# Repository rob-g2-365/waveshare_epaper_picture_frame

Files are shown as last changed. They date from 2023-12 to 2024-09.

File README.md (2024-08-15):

# Waveshare Epaper Picture Frame

# Table of Contents
* [Introduction](#Introduction)
* [Knowledge Assumptions](#Knowledge-Assumptions)
* [File List](#File-List)
* [Specifications](#Specifications)
* [Parts List](#Parts-List)
* [Other Equipment Needed](#Other-Equipment-Needed)
* [Printing Instructions](#Printing-Instructions)
* [PCB Board Instructions](#PCB-Board-Instructions)
* [Assembly Instructions](#Assembly-Instructions)
* [Arduino Code ](#Arduino-Code)
* [Python Code](#Python-Code)
* [SD Card](#SD-Card)
* [Testing and Putting it Together](#Testing-and-Putting-it-Together)
* [Battery Life and Power Consumption](#Battery-Life-and-Power-Consumption)
* [Additional Resources](#Additional-Resources)

## Introduction

This project displays an image on an e-paper picture frame.  The picture switches once per day.  Included are the list of materials and how to build it.

E Picture frame display

## Knowledge Assumptions
I am assuming in this project that the user knows how to do the following:

* Read an electrical schematic.
* Basic soldering of through-hole components.
* Configure and build a project using the Arduino IDE.
* Slice a 3d Model and send it to a 3d printer.
* Put brass inserts into plastic using a soldering iron.
* Run a Python script.

## File List

* [Documentation](./docs)
* [Gerber files](./gerber)
* [STL Files](./stl)
* [Freecad code](./freecad)
* [Arduino IDE code](./arduino)
* [Convert Images Script](./convert_images)
* [Sample SD Card Image](./sdcard_image)
* [License file](.license)

## Specifications

* Display Size 5x7 inches or 10x18cm.
* Battery life should be about a year with alkaline batteries.

## Parts List

### Basic Parts
| Item | Quantity  		 | Notes |
| :--- | :--- 		 | :--- |
| PLA | 400g 		 | Used just plain black PLA |
| Picture frame  | 1 | [Used 5x7 Vertical Side Natural Frame by Threshold from Target](https://www.target.com/p/5--34--x-7--34--vertical-sides-natural-frame-antique-wood---threshold--8482-/-/A-54562757) |
| Solder | Small Amount | |

### Fasteners

| Item | Quantity  		 | Notes |
| :--- | :--- 		 | :--- |
| M2 x 6mm Phillips Flat Countersunk Head Machine Screws	| 2 |  |
| M2.5 x 8mm Phillips flathead Machine Screws | 2 |  |
| \#4 x 1/2 inch Wood Screws | 5 | Alternative use M3 x 15mm Woodscrews |
| M2.5 x 5mm Pan Phillips Cross Head Machine screws | 12 |  You could just use the flathead screws for all screws M2.5 screws |
| M2 x 4mm Brass Inserts	 | 14 | |
| M2.5 x 5.8mm Brass Inserts | 12 |  There is room for longer inserts. |

### Electrical Parts

Note that all electronic parts are through-hole components.  Note that many substitutes can be used for the resistors, capacitors, and diode.

| Item 									 | Part Number 																						| Quantity  |
| :--- 									 | :--- 																				| :--- |
| Waveshare 7.3 inch ACeP 7-Color E-Paper 800x600 | [7.3 inch e-Paper Hat (F)](https://www.waveshare.com/product/displays/e-paper/7.3inch-e-paper-hat-f.htm) | 1 |
| MicroSD Card | MicroSD Card | 1 |
| MicroSD Card Adapter for Arduino | [MicroSD Card Adapter](https://www.amazon.com/Storage-Memory-Shield-Module-Arduino/dp/B01IPCAP72) | 1 |
| 3 AAA Battery Holder | [3 AAA Battery Holder](https://www.amazon.com/Velleman-BH431A-Battery-Holder-AAA-Cell/dp/B003TZDNN4) | 1 |  
| ATmega328-P-PU Arduino Bootloader | [3647-ATMEGA328P-PUArduinoBootloader-ND](https://www.digikey.com/en/products/detail/universal-solder-electronics-ltd/ATMEGA328P-PU-Arduino-Bootloader/16822123)  | 1 | 
| 28 Pin DIP Socket | [ICM-328-1-GT-HT](https://www.digikey.com/en/products/detail/adam-tech/ICM-328-1-GT-HT/9832998) | 1 |
| PMOS - LP0701N3-G | [LP0701N3-G-ND](https://www.digikey.com/en/products/detail/microchip-technology/LP0701N3-G/4902364) | 1 |
| 22pF Capacitor | [K220J15C0GF5TL2](https://www.digikey.com/en/products/detail/vishay-beyschlag-draloric-bc-components/K220J15C0GF5TL2/286459) | 2 |
| 100nF	Capacitor 							 | [K104K15X7RF5TL2](https://www.digikey.com/en/products/detail/vishay-beyschlag-draloric-bc-components/K104K15X7RF5TL2/286538) | 3 |
| Diode General Purpose | [BAW75-TAP](https://www.digikey.com/en/products/detail/vishay-general-semiconductor-diodes-division/BAW75-TAP/4825763) | 1 |
| 10K Resistor | [CF14JT10K0](https://www.digikey.com/en/products/detail/stackpole-electronics-inc/CF14JT10K0/1741265) | 1 |
| 100K Resistor | [CF14JT100K](https://www.digikey.com/en/products/detail/stackpole-electronics-inc/CF14JT100K/1741263) | 2 | 
| SW_Push SWITCH TACTILE SPST | [B3F-1000](https://www.digikey.com/en/products/detail/omron-electronics-inc-emc-div/B3F-1000/33150) | 1 | 
| 16Mhz 20pF Crystal | [ECS-160-20-1X](https://www.digikey.com/en/products/detail/ecs-inc/ECS-160-20-1X/827525) | 1 |

We need a package of straight DuPont-style male row connectors in order to make the 1x2, 1x6, and 1x8 Connectors.  Also (10Cm) short multicolor Dupont Female to Female wires.

Note that the Micro SD Card doesn't need much capacity.  A 1Gb Micro SD Card should work.

## Other Equipment Needed

### Other Hardware Needed

* 3D Printer
* Soldering Iron
* [Arduino FTDI USB to Serial 5v Programmers](https://www.amazon.com/Serial-Adapter-Female-FT232RL-Windows/dp/B07RBK2P47) 

Also, it is a good idea to have troubleshooting equipment such as a multimeter and something to decode the SPI bus traffic.

### Software Needed

Need the software [Arduino IDE](https://www.arduino.cc/en/software) to build and download the code. I used version 2.1.0, but the latest version probably would work for you.

#### Arduino IDE Packages

| Package 														| Owner 			  | Current Version |
| :--- 														| :---  			  | :--- |
| Arduino Builtin | Arduino | Built Into IDE  |
| [SD](https://www.arduino.cc/reference/en/libraries/sd/) 	| Arduino SparkFun | 1.2.4 |
| [LowPower_LowPowerLab](https://www.arduino.cc/reference/en/libraries/lowpower_lowpowerlab/)  | LowerPowerLab | 2.2 			|
| [EEPROM](https://docs.arduino.cc/learn/built-in-libraries/eeprom)	 | Arduino | Built Into IDE  |
| [SPI](https://www.arduino.cc/reference/en/language/functions/communication/spi/) | Arduino | Built Into IDE  |

### Python Environment

I used Python 3.9 with the Pillow (Python Image Library) 9.3.0 package installed.  The latest of each should work.

#### Optional Software

| Package 				| Version Used |
| :--- 				| :---  	 |
| Freecad | 0.21.2 |
| KiCad | 7.0 |

## Printing Instructions

### Printer Settings

| Settings  |  Used |  Notes |
| :--- | :--- | :--- |
| Material  | PLA | |
| Nozzle | 0.4mm | |
| Layer Height | 0.2mm | |
| Walls | 5 | Needed for Brass Inserts |
| Infill | 20% | |
| Supports  | Only Touching Build plate | |

### 3D Printed Parts List

| Part 	|  Picture |
| :--- 	| :--- |
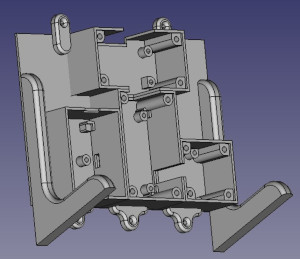
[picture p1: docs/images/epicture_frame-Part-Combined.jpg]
Main Part
| Main Part 	|  |
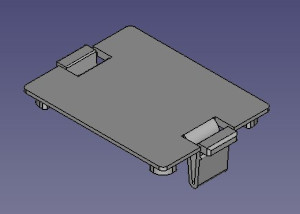
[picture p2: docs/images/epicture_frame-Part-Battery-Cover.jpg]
Battery Cover
| Battery Cover 	|   |
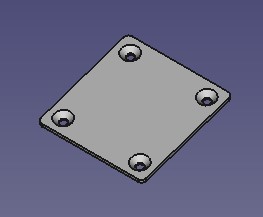
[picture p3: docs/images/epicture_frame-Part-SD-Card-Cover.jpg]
SD Card Cover
| SD Card Cover 	|   |
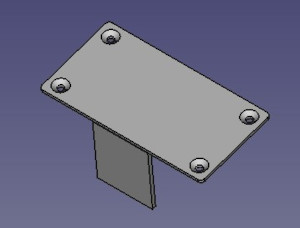
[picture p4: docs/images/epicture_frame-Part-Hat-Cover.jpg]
Display HAT Cover
| Display HAT Cover |  |
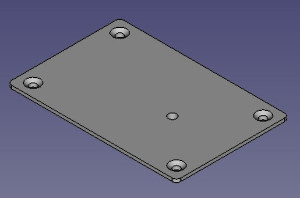
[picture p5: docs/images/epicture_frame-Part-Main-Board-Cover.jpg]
Main Board Cover
| Main Board Cover  |   | 
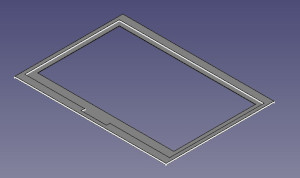
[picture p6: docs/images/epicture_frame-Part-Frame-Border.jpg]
Frame Border
| Frame Border |   |

## PCB Board Instructions

Gerber files are listed in the gerber directory.    I used OshPark to create the PCBs, but you should be able to use other vendors.

## Assembly Instructions

### Insert the M2.5 Brass Inserts into the Following Holes

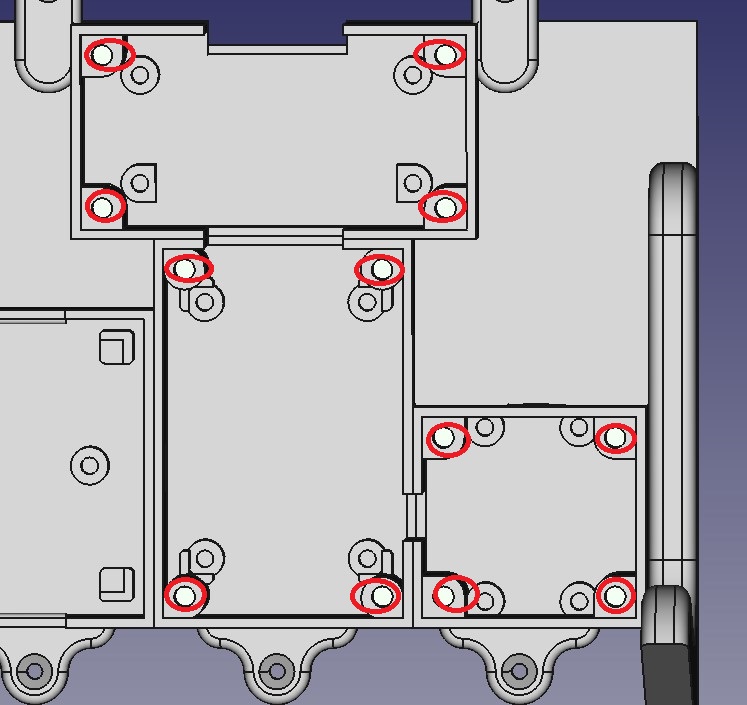
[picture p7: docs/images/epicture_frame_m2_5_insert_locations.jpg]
M2.5 Brass Insert Locations


Use a solder gun to insert the brass inserts.

### Insert the M2 Brass Inserts into the Following Holes

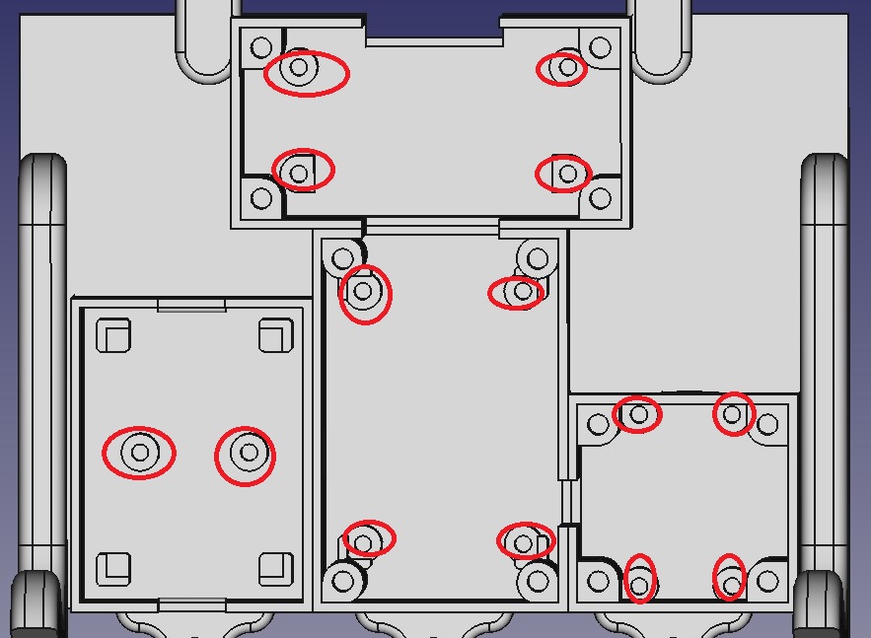
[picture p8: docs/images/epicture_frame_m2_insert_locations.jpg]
M2 Brass Insert Locations


### Solder Components to PCB Board

Solder components to the PCB board.  The silkscreen shows the Component number location.

| Component Number | Part  |
| :--- | :---  |
| C1, C2 | 22pF  | 
| C3, C4, C5 | 100nF |
| D1 | General Purpose Diode |
| J1, J2 | Male Connector 01x06 Pin |
| J3	 | Male Connector 01x08 Pin |
| J4	 | Male Connector 01x02 Pin |
| Q1	 | PMOS - LP0701N3-G |
| R1 | 10K Resistor |
| R2, R3	 | 100K Resistor |
| SW1 | Push button switch |
| U1	 | 28 Pin Connector for ATmega328-P |
| Y1	 | 16Mhz Crystal |

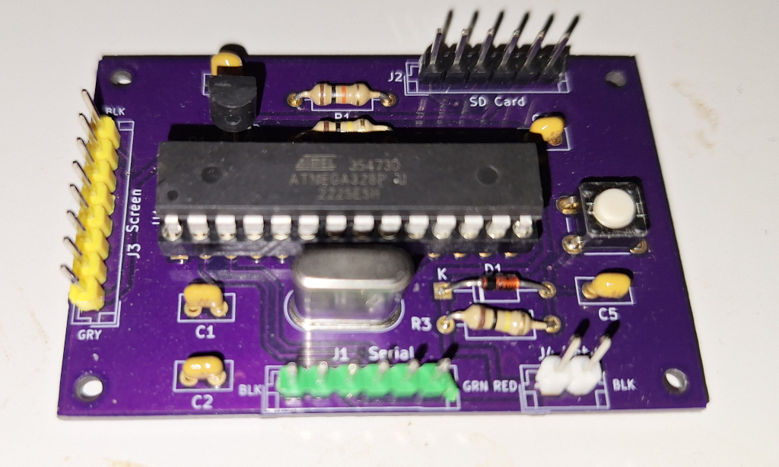
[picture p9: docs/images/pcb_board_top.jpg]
PCB board


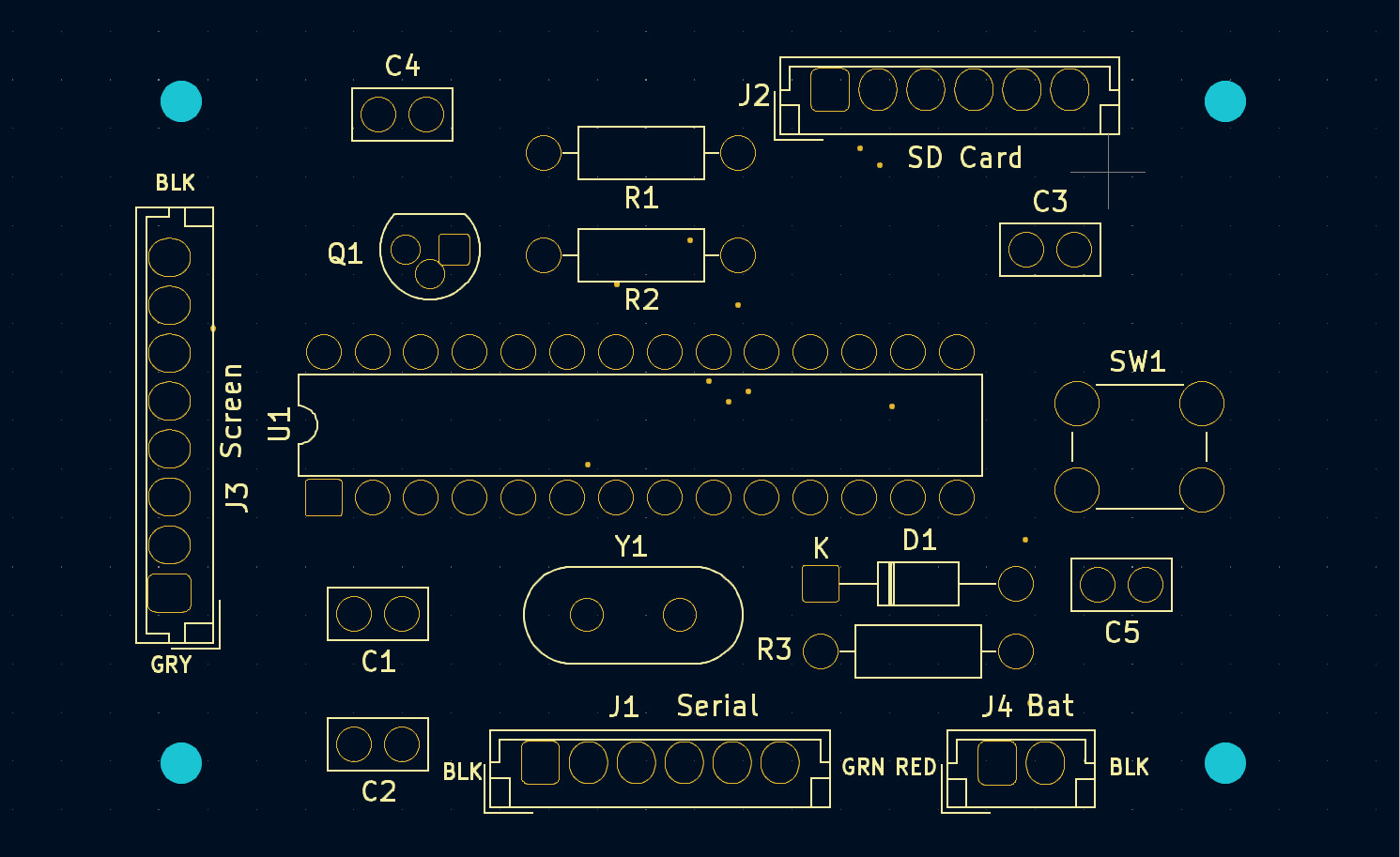
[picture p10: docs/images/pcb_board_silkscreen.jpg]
PCB board Silk Screen


### Assemble the Main Part to Frame

Remove the original back assembly from the picture frame. We do not need the back of the picture frame, the screws, or the stand.  We only need the picture frame and the glass.

Mark Drill Holes.  (See frame back picture)
Drill holes into the picture frame using a 5/64 or 2mm drill bit.

Remove any stickers from the glass. Clean glass the glass using glass cleaner or isopropyl alcohol.   Ensure that no fingerprints are on the inside glass. 

Assemble in the following order:

1.  Wooden Frame
2.  Glass
3.  3D Printed Frame border
4.  E-paper display (Be sure the protective covering is removed and the e-paper display ribbon cable is at the top.)
5.  3D Printed Main Body

Use the #4 wood screw holes to attach the 3D Printed main body to the wooden picture frame.

### Put Boards into Main Picture Frame

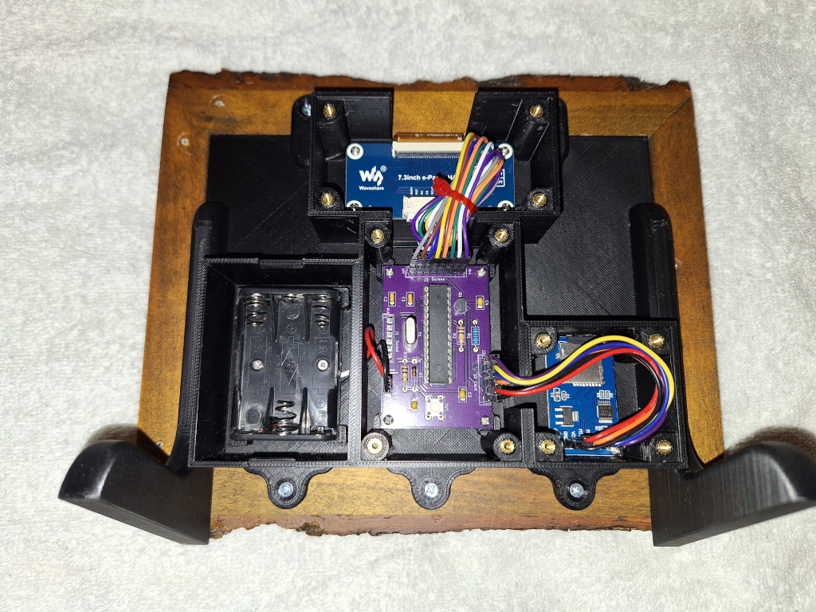
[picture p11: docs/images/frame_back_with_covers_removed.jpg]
Frame Back


### Connect the Ribbon Cable to the E-Hat

The extension cable for the e-paper display is not needed.   Connect the ribbon cable from the display to the e-hat.  Use M2 roundhead screws to attach the e-hat.

### Attach the Battery Case

Push battery wires through the holes in the main body.  Attach the battery case using M2 Flathead screws.

### Attach the Other Components to the Main Board

SD Card Adapter and Main Board used M2 Roundhead screws.  Be sure that the hole in the main body for the SD Card matches the SD Card slot.

Attach the main PCB board.  Ensure that the J3 screen is next to the hat connector and the SW1 is at the bottom of the display. 

### Make Connections to PCB Board

Attach the battery to J4.  PCB board is marked red for positive and black for negative.

Attach SD card connections to J2.  Chip select is closest to R1.  Please double-check [schematic](./docs/schematic.pdf).

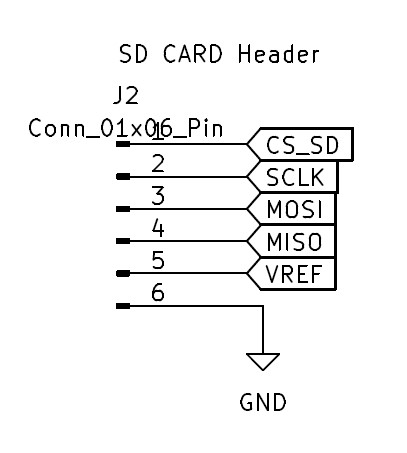
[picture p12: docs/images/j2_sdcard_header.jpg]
J2 SD Card Header


Attach the Waveshare e-hat SPI connections to J3.  Gray should match GRY on the board.  Note that the BLK wire may be purple.

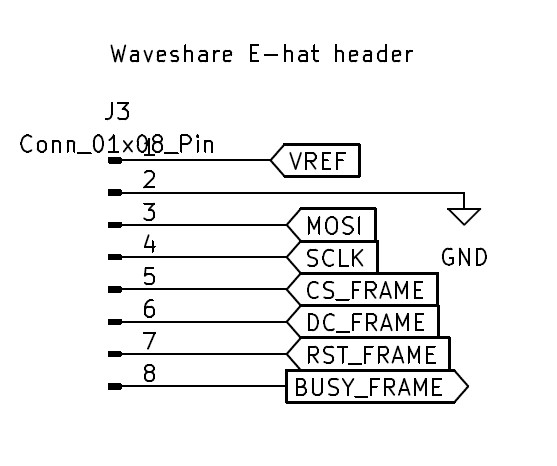
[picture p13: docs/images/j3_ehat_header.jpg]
J3 Waveshare E-hat header


## Arduino Code 

### Arduino Code Overview

I had to make a couple of changes to the Waveshare drivers.  They are:

   A.  Changes with Waveshare drivers (SPI frequency and chips select)
   B.  Reduced the SPI clock speed.

### Download Instructions

Use Board type "Arduino Uno"

Attach FTDI USB to serial connector to J1 serial connector. 

### Enable Serial Debug

If you run into problems, you may want to enable serial debugging.  To enable serial debug out, uncomment line 50. 

<pre>
// Include this flag to turn on serial logging.
// #define SERIAL_DEBUG
</pre>

The last failure is saved in the EEPROM.  When booting, the error code is outputted over the serial port.   The error codes are listed in line 36 of debug.h.
<pre>
#define ERRORCODE_TEST                        0
#define ERRORCODE_EPAPER_INIT_FAILED          0x101
.
.
</pre>

## Python Code

### Preprocessing Portrait Images

Images that are formatted as portrait may need to be cropped so that faces and important details may be shown.

### Python Command-line Arguments

<pre>
	convert_images.py &lt;Source Directory&gt;  &lt;Destinations Directory&gt;
</pre>	
	
This command converts images from the source directory or its children into the destination directory.

Images in the destination directory are listed in the following order:  pic_000.bmp, pic_001.bmp, pic_002.bmp, etc.

This program also does the following:  

1.  Auto-adjusts the contrast.
2.  Increases the saturation so the images don't look washed out.
3.  Mirrors the image to looks correct when viewed from the picture frame.
4.  Crops the image so the image size is correct.
5.  Dithers the images so that only seven colors are needed to display the image.
6.  Randomizes the image's order.

## SD Card

### Sample SD Card Image

A sample SD Card image is located in:

Sample SDCard Image

### SD Card Format and Files

The Micro SD Card capacity can be small since the images don't occupy much space.  Format a Micro SD Card using Fat32.  Copy the processed image files to the root of the Micro SD Card.

Insert the Micro SD Card into the Micro SDCard Adapter for Arduino.

## Testing and Putting it Together

Verify that the image appears on the e-paper display.

Attach the 3D-printed covers.  

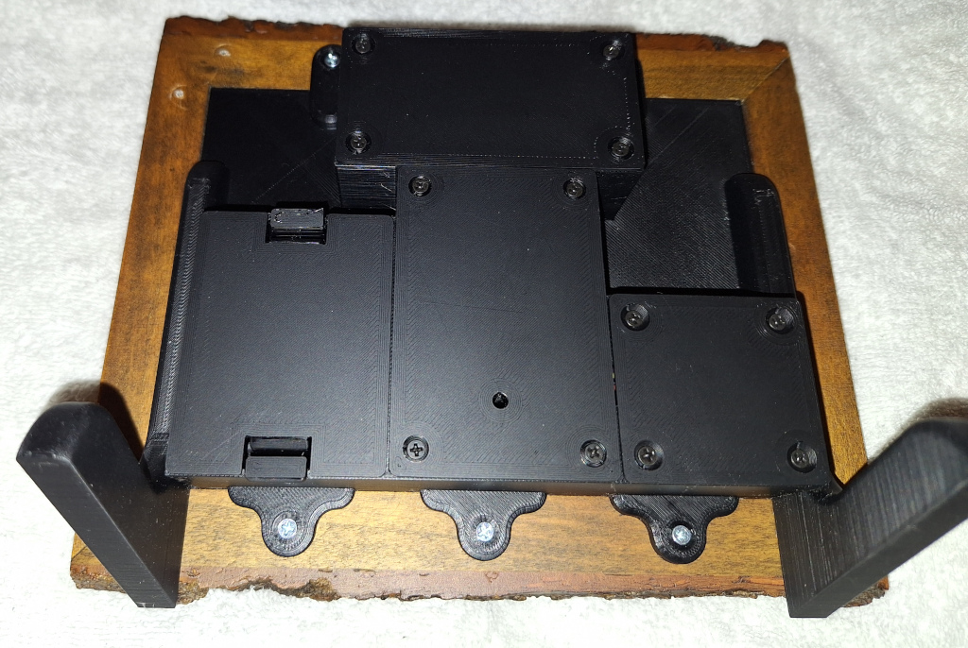
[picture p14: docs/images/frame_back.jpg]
Picture Frame Back


## Battery Life and Power Consumption

It takes about 134 seconds to change the image on the screen.  During this time, it uses approximately 40mA. 

$$ = 134 (seconds/switch) * 40 (mA) / 3600 (seconds/hour) $$

$$ = 1.5 (mAh/switch) $$

When idle, the current draw is about 10 uA.

$$ =  24 (hours) * 0.01 (mA) $$

$$ = 0.3 (mAh) $$

An approximate alkaline AAA battery life is about 1200mAh.  However, the picture frame cannot use the full capacity of the battery.  
Once the voltage goes below 3.8v, 1.25v per cell, the picture frame will stop working.  This is about 50% of the capacity.

Therefore, the battery life for the picture frame is:

$$ = 1200 mAh * 50% / 1.8 (mAh/ day) $$

$$ = 333 (days) $$

## Possible improvements.

### Use a ultra low I<sub>Q</sub> Boost Converter

An ultra-low I<sub>Q</sub> boost converter is one option for more battery life.  This will allow the battery pack voltage to be functional down 
to 2.7v, which is using the battery's full capacity. I don't know if using the full capacity of the battery will offset the leakage power lost through the boost converter.

## Additional Resources

[Waveshare 7.3inch e-Paper HAT (F) Manual](https://www.waveshare.com/wiki/7.3inch_e-Paper_HAT_(F))

[e Paper with Arduino and Raspberry Pi](https://www.youtube.com/watch?v=4onIqHClh2s&t=601s)

[Trolling My Mom With an E-Paper Picture](https://youtu.be/YawP9RjPcJA)

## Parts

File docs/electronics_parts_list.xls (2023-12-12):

Source: | C:\work\arduino\kicad\epaper_board_layout\epaper_board_layout\epaper_board_layout.kicad_sch
Date: | 4/21/2023 1:44:44 PM
Tool: | Eeschema 7.0.1
Generator: | C:\Program Files\KiCad\7.0\bin\scripting\plugins/bom_csv_grouped_by_value.py
Component Count: | 17
Collated Components:
Item | Qty | Reference(s) | Value | LibPart | Footprint | Datasheet | DNP | Sim.Device | Sim.Pins | Sim.Type
1 | 2 | C1, C2 | 22pF | Device:C | Capacitor_THT:C_Disc_D5.0mm_W2.5mm_P2.50mm | https://www.digikey.com/en/products/detail/vishay-beyschlag-draloric-bc-components/K220J10C0GF5UH5/2821614
2 | 3 | C3, C4, C5 | 100nF | Device:C | Capacitor_THT:C_Disc_D5.0mm_W2.5mm_P2.50mm | https://www.digikey.com/en/products/detail/vishay-beyschlag-draloric-bc-components/K104K15X7RF53H5G/13279844
3 | 1 | D1 | D | Device:D | Diode_THT:D_DO-35_SOD27_P10.16mm_Horizontal | https://www.digikey.com/en/products/detail/vishay-general-semiconductor-diodes-division/BAW75-TAP/4825763 |  | D | 1=K 2=A
4 | 2 | J1, J2 | Conn_01x06_Pin | Connector:Conn_01x06_Pin | Connector_JST:JST_EH_B6B-EH-A_1x06_P2.50mm_Vertical | ~
5 | 1 | J3 | Conn_01x08_Pin | Connector:Conn_01x08_Pin | Connector_JST:JST_EH_B8B-EH-A_1x08_P2.50mm_Vertical | ~
6 | 1 | J4 | Conn_01x02_Socket | Connector:Conn_01x02_Socket | Connector_JST:JST_EH_B2B-EH-A_1x02_P2.50mm_Vertical | ~
7 | 1 | Q1 | PMOS - LP0701N3-G | Simulation_SPICE:PMOS | Package_TO_SOT_THT:TO-92 | https://www.digikey.com/en/products/detail/microchip-technology/lp0701n3-g/4902364 |  | PMOS | 1=D 2=G 3=S | VDMOS
8 | 1 | R1 | 10K | Device:R | Resistor_THT:R_Axial_DIN0207_L6.3mm_D2.5mm_P10.16mm_Horizontal | https://www.digikey.com/en/products/detail/stackpole-electronics-inc/CF14JT10K0/1741265
9 | 1 | R2 | 100K | Device:R | Resistor_THT:R_Axial_DIN0207_L6.3mm_D2.5mm_P10.16mm_Horizontal | https://www.digikey.com/en/products/detail/stackpole-electronics-inc/RNF14BTE100K/1682686
10 | 1 | R3 | 100k | Device:R | Resistor_THT:R_Axial_DIN0207_L6.3mm_D2.5mm_P10.16mm_Horizontal | https://www.digikey.com/en/products/detail/stackpole-electronics-inc/RNF14BTE100K/1682686
11 | 1 | SW1 | SW_Push | Switch:SW_Push | Button_Switch_THT:SW_PUSH_6mm_H5mm | https://www.digikey.com/en/products/detail/omron-electronics-inc-emc-div/B3F-1000/33150
12 | 1 | U1 | ATmega328-P | MCU_Microchip_ATmega:ATmega328-P | Package_DIP:DIP-28_W7.62mm | http://ww1.microchip.com/downloads/en/DeviceDoc/ATmega328_P%20AVR%20MCU%20with%20picoPower%20Technology%20Data%20Sheet%2040001984A.pdf
13 | 1 | Y1 | 16Mhz | Device:Crystal | Crystal:Crystal_HC49-4H_Vertical | https://www.digikey.com/en/products/detail/ecs-inc/ECS-160-20-1X/827525

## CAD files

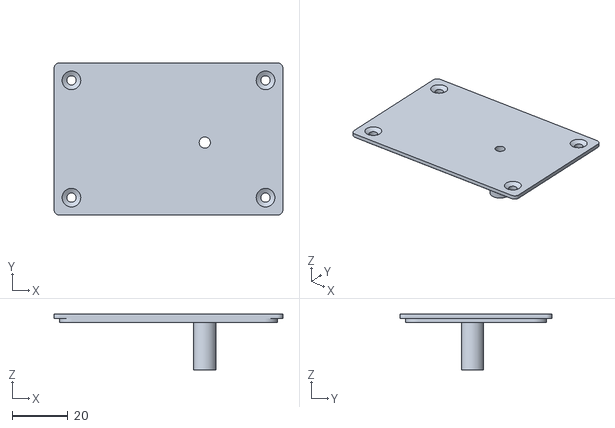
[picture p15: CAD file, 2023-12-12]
stl/epicture_frame-Part_Main_Board_Cover.stl
82.0 x 54.5 x 20.0

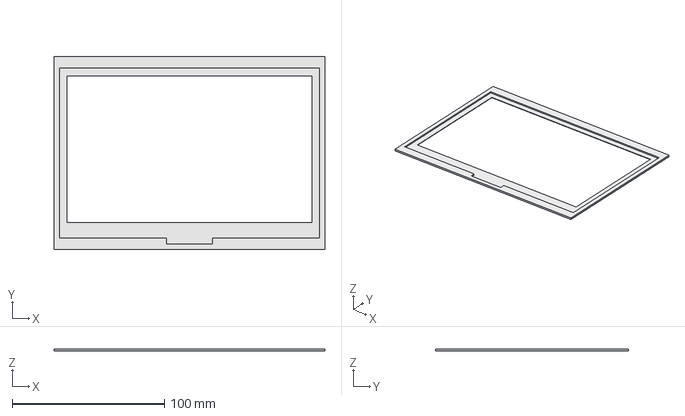
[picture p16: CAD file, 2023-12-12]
freecad/picture_frame_border.FCStd
178.0 x 127.0 x 1.50 mm

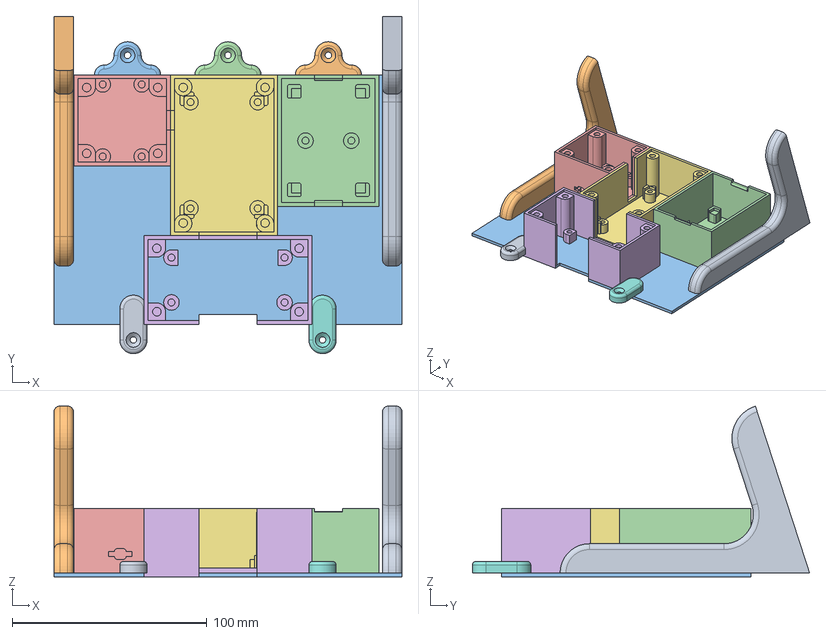
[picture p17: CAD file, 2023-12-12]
freecad/epicture_frame.FCStd
178.5 x 173.0 x 87.6 mm
Body Combined Support 1
Body Combined Support 2
Body Combined Back
Body Combined Battery
Body Combined SD Card
Body Combined Hat
Body Combined Board
Body Back Screw Tab Clone 1
Body Back Screw Tab Clone 2
Body Back Walled Screw Tab Clone 1
Body Back Walled Screw Tab Clone 2
Body Back Walled Screw Tab Clone 3

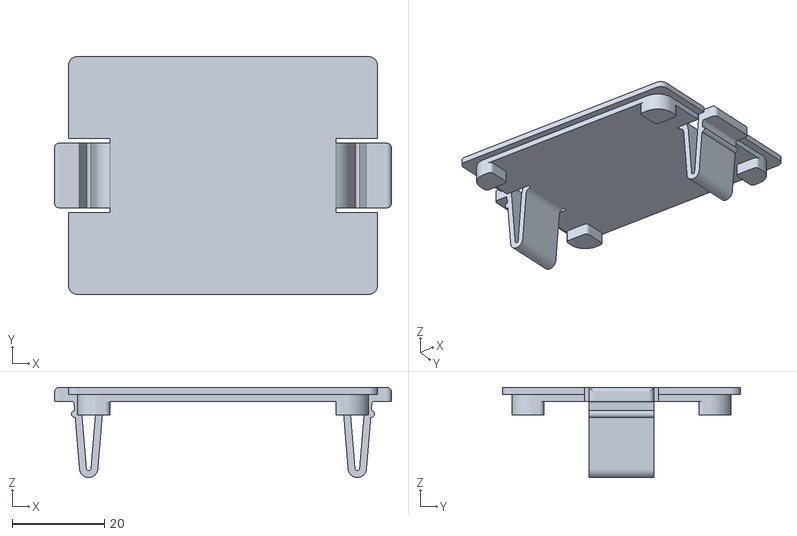
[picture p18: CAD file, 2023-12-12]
stl/epicture_frame-Part_Battery_Cover.stl
73.0 x 51.5 x 19.5

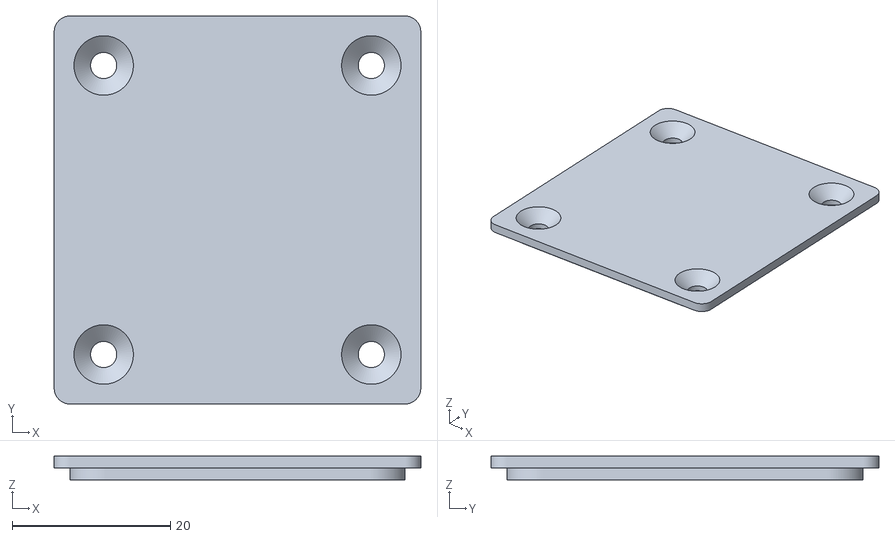
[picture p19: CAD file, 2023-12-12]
stl/epicture_frame-Part_SD_Card_Cover.stl
46.3 x 49.0 x 3.00

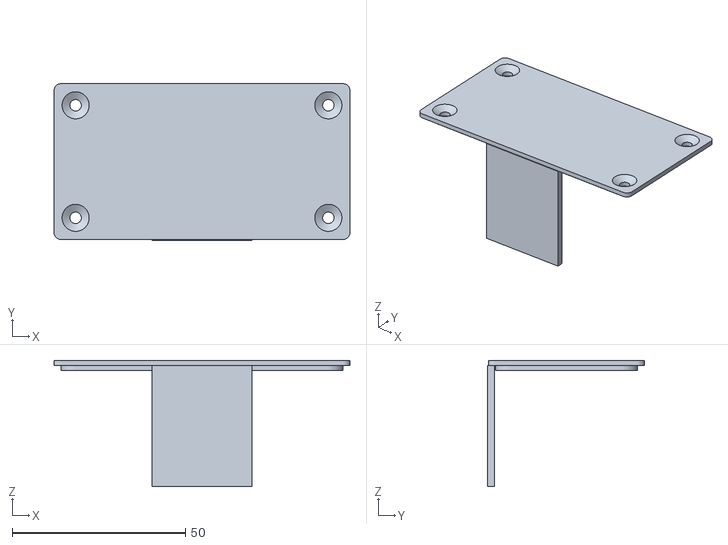
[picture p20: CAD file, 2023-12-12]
stl/epicture_frame-Part_Hat_Cover.stl
85.5 x 45.2 x 36.5

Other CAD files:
stl/epicture_frame-Part_Border.stl
stl/epicture_frame-Part_Combined.stl

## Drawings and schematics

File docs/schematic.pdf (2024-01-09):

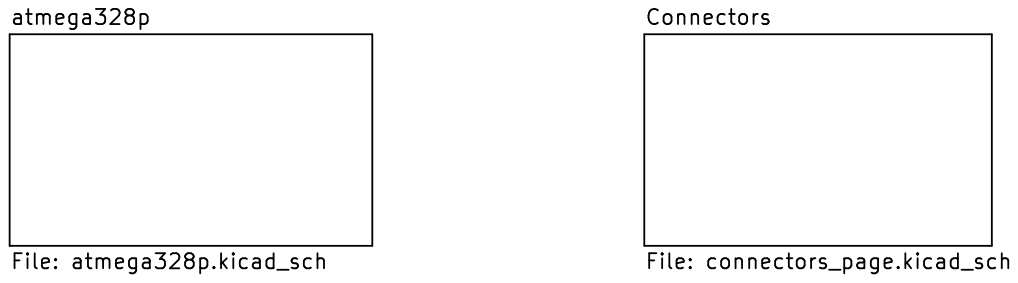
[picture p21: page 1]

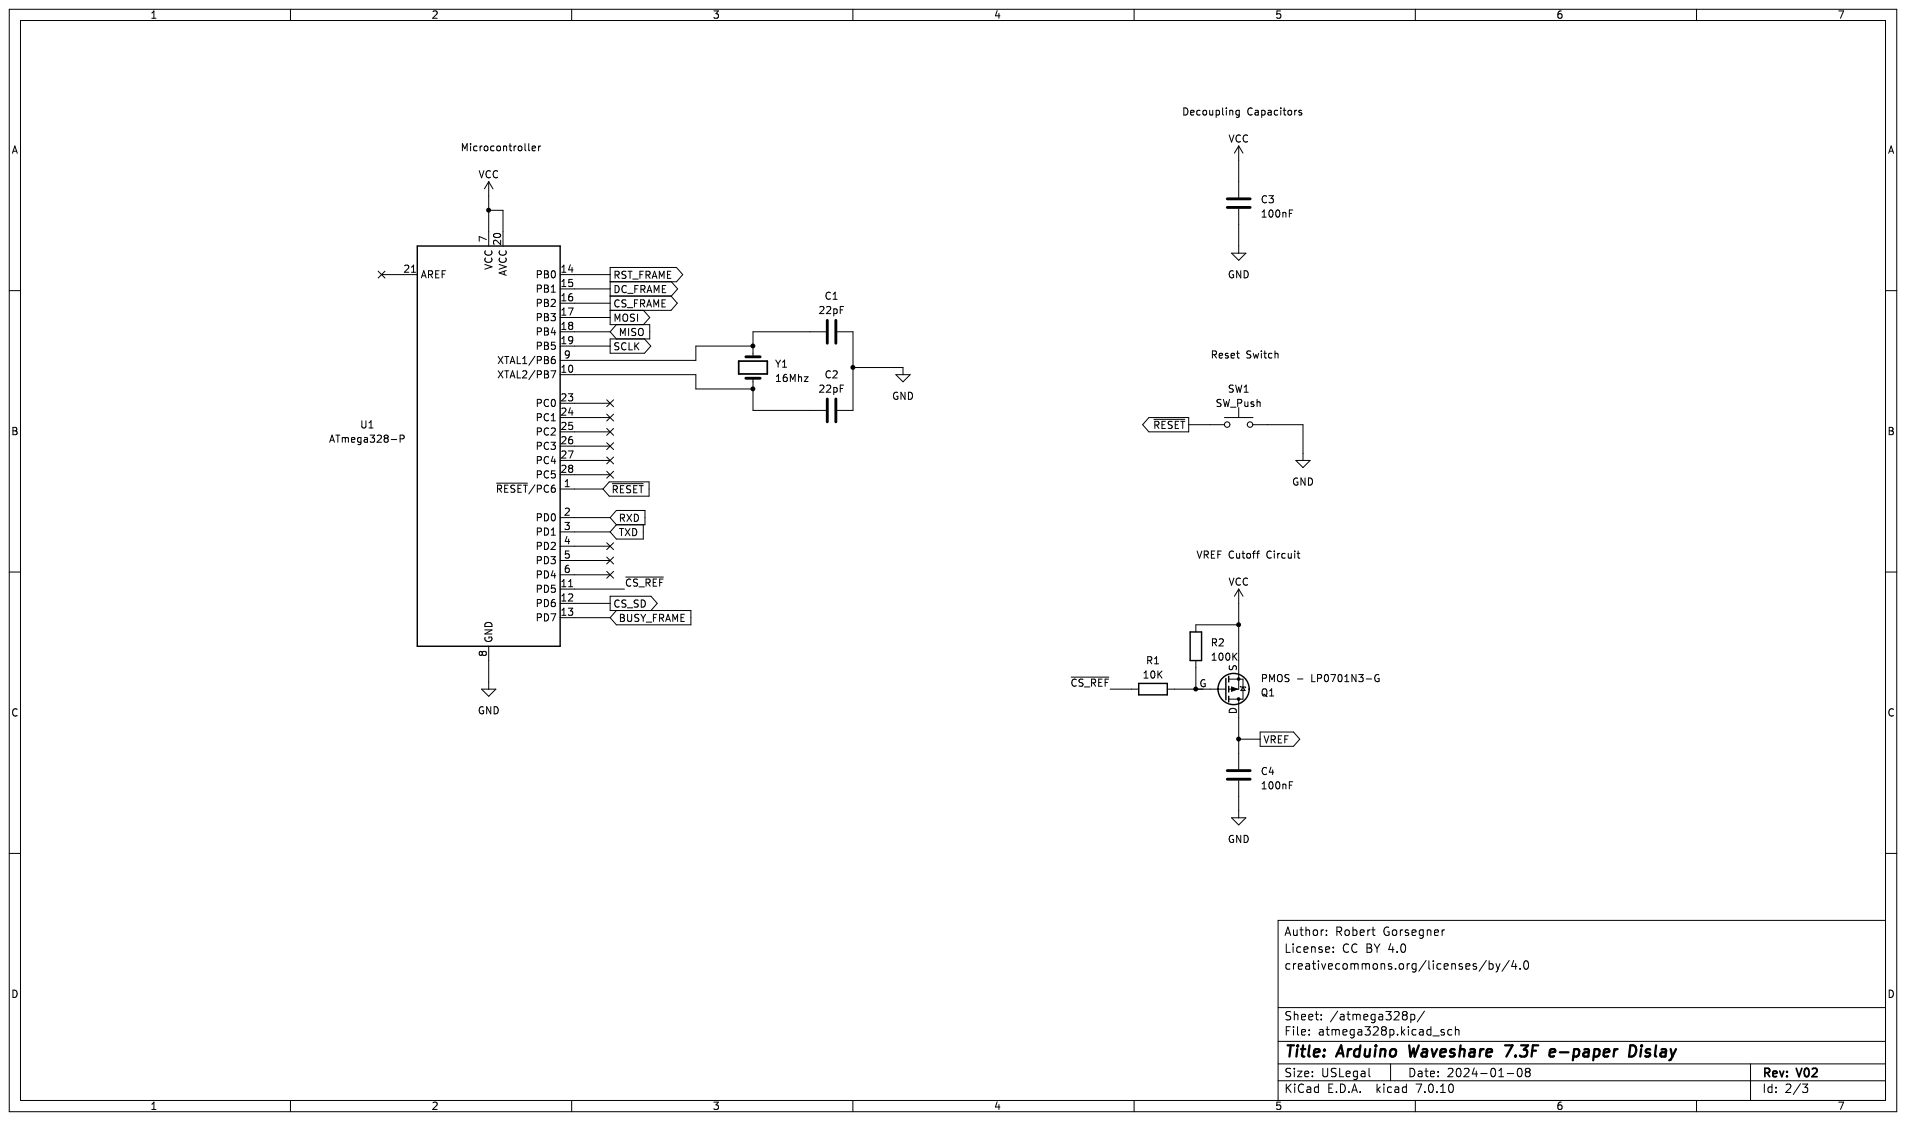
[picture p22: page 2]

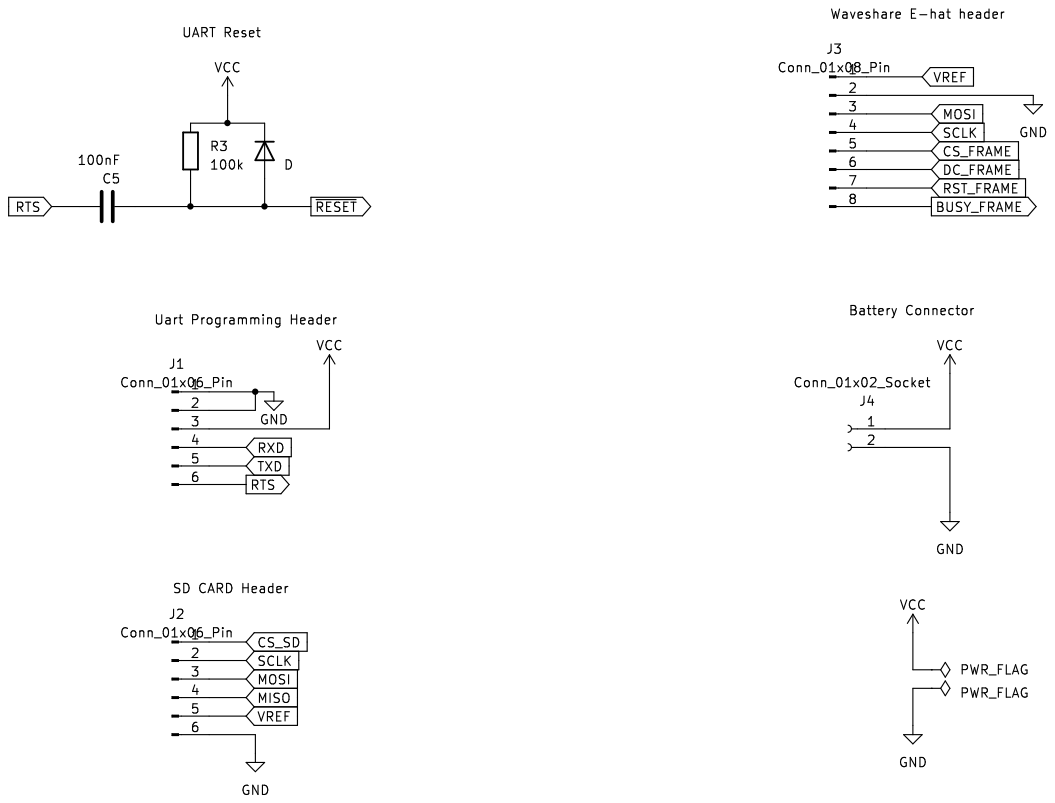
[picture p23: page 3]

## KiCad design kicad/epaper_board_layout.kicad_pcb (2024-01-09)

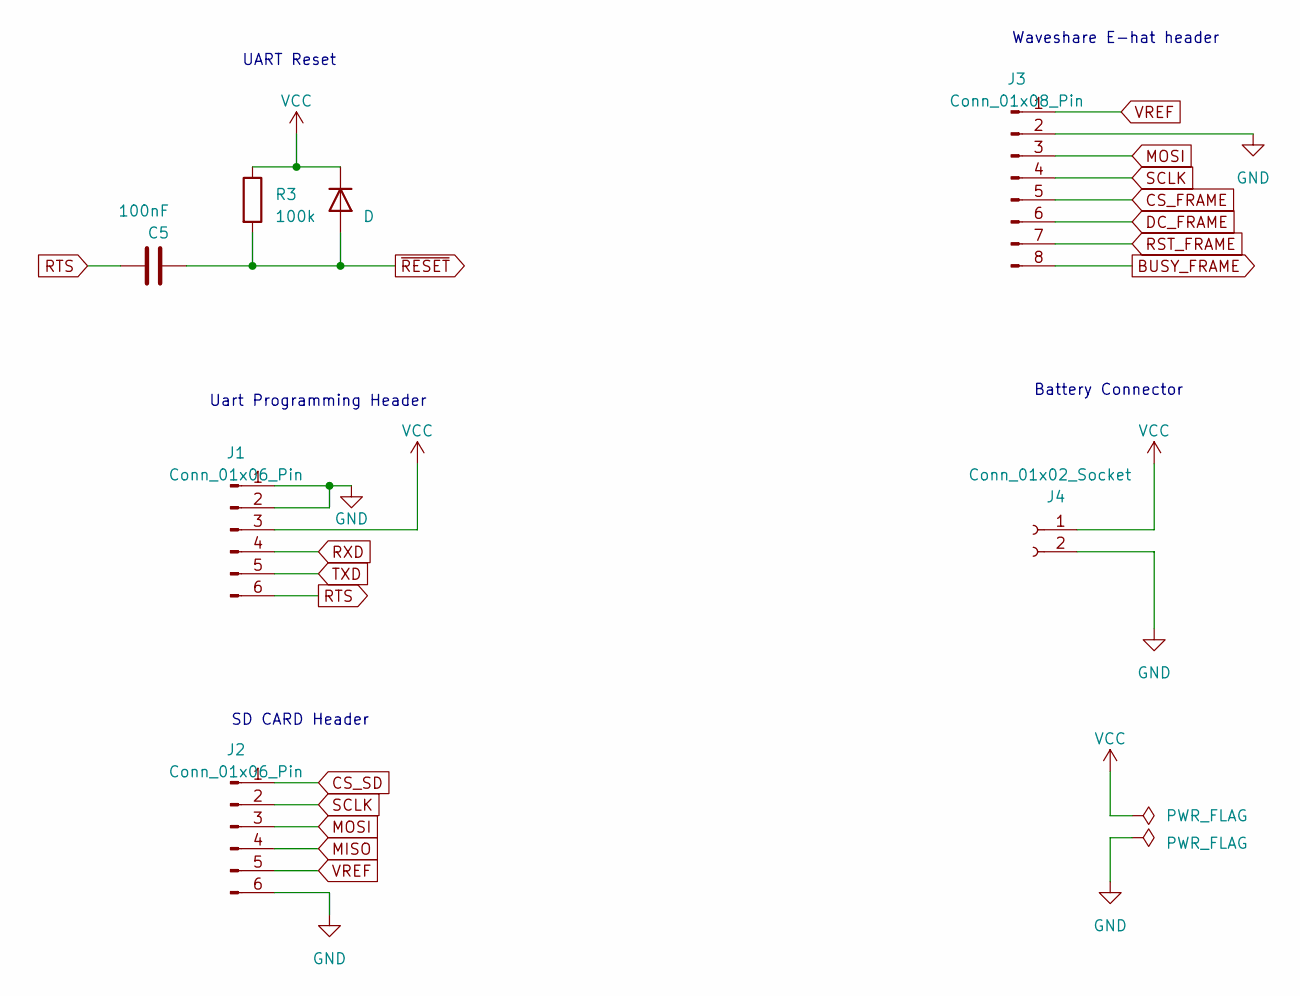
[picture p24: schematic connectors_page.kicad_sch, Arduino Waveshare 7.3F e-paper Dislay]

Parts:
C5: 100nF; C_Disc_D5.0mm_W2.5mm_P2.50mm
D1: D; D_DO-35_SOD27_P10.16mm_Horizontal
J1, J2: Conn_01x06_Pin; JST_EH_B6B-EH-A_1x06_P2.50mm_Vertical
J3: Conn_01x08_Pin; JST_EH_B8B-EH-A_1x08_P2.50mm_Vertical
J4: Conn_01x02_Socket; JST_EH_B2B-EH-A_1x02_P2.50mm_Vertical
R3: 100k; R_Axial_DIN0207_L6.3mm_D2.5mm_P10.16mm_Horizontal

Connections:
BUSY_FRAME: J3.8; also elsewhere on the board
CS_FRAME: J3.5; also elsewhere on the board
CS_SD: J2.1; also elsewhere on the board
DC_FRAME: J3.6; also elsewhere on the board
GND: J1.1, J1.2, J2.6, J3.2, J4.2; also elsewhere on the board
MISO: J2.4; also elsewhere on the board
MOSI: J2.3, J3.3; also elsewhere on the board
RST_FRAME: J3.7; also elsewhere on the board
RTS: C5.1, J1.6
RXD: J1.4; also elsewhere on the board
SCLK: J2.2, J3.4; also elsewhere on the board
TXD: J1.5; also elsewhere on the board
VCC: D1.1 (K), J1.3, J4.1, R3.1; also elsewhere on the board
VREF: J2.5, J3.1; also elsewhere on the board
~RESET: C5.2, D1.2 (A), R3.2; also elsewhere on the board

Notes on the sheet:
Waveshare E-hat header
SD CARD Header
Battery Connector
UART Reset
Uart Programming Header

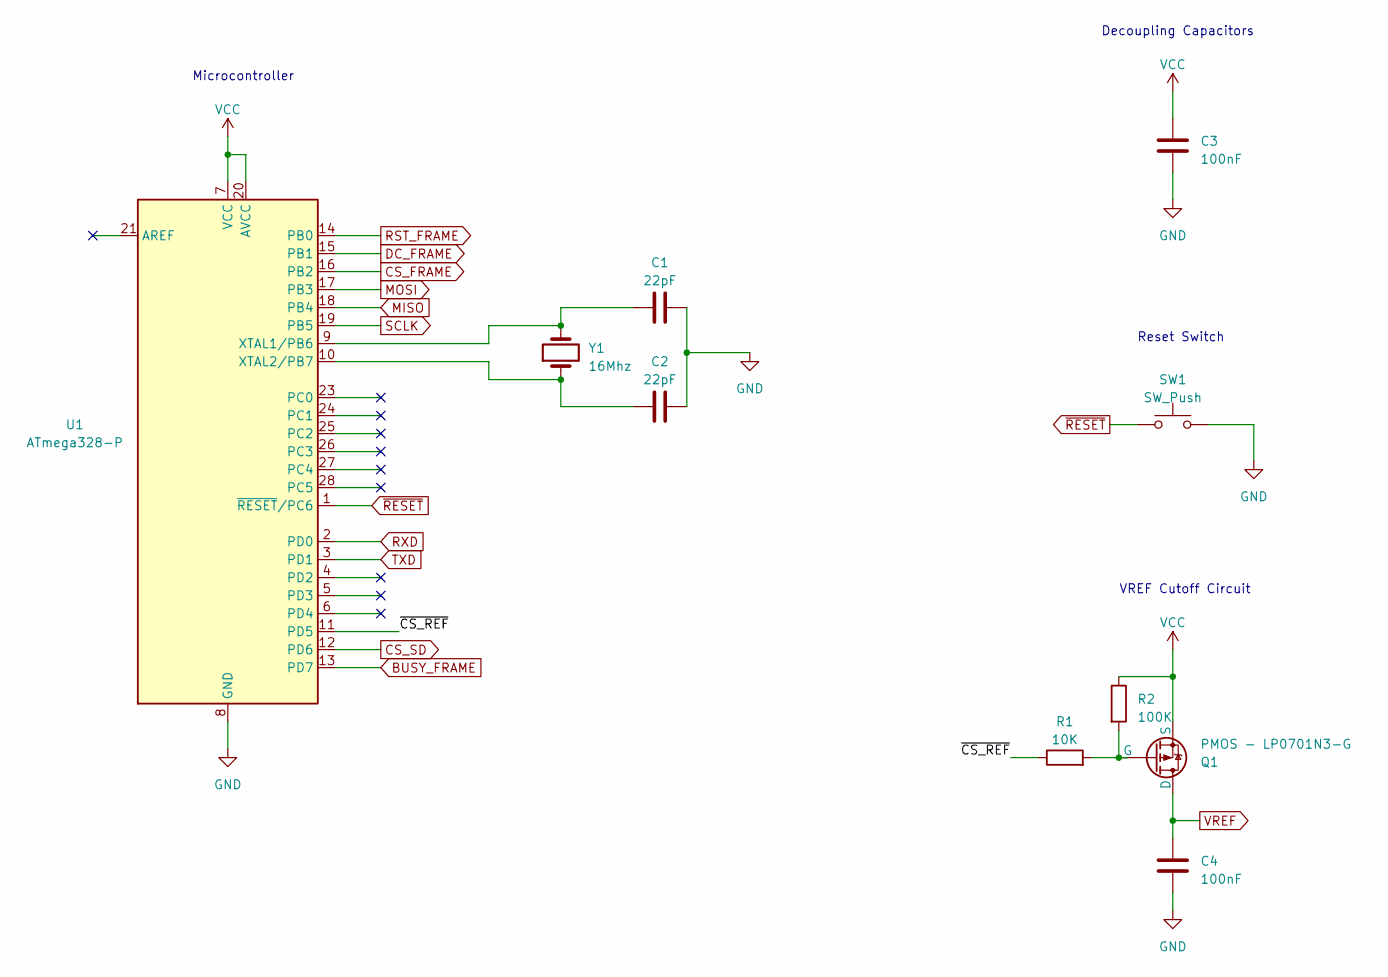
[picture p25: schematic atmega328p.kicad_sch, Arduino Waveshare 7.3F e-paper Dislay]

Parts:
C1, C2: 22pF; C_Disc_D5.0mm_W2.5mm_P2.50mm
C3, C4: 100nF; C_Disc_D5.0mm_W2.5mm_P2.50mm
Q1: PMOS - LP0701N3-G; TO-92
R1: 10K; R_Axial_DIN0207_L6.3mm_D2.5mm_P10.16mm_Horizontal
R2: 100K; R_Axial_DIN0207_L6.3mm_D2.5mm_P10.16mm_Horizontal
SW1: SW_Push; SW_PUSH_6mm_H5mm
U1: ATmega328-P; DIP-28_W7.62mm
Y1: 16Mhz; Crystal_HC49-4H_Vertical

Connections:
/atmega328p/~CS_REF: R1.1, U1.11 (PD5)
BUSY_FRAME: U1.13 (PD7); also elsewhere on the board
CS_FRAME: U1.16 (PB2); also elsewhere on the board
CS_SD: U1.12 (PD6); also elsewhere on the board
DC_FRAME: U1.15 (PB1); also elsewhere on the board
GND: C1.2, C2.2, C3.2, C4.2, SW1.2, U1.8 (GND), U1.22 (GND); also elsewhere on the board
MISO: U1.18 (PB4); also elsewhere on the board
MOSI: U1.17 (PB3); also elsewhere on the board
unnamed: Q1.2 (G), R1.2, R2.2
unnamed: C1.1, U1.9 (XTAL1/PB6), Y1.2
unnamed: C2.1, U1.10 (XTAL2/PB7), Y1.1
RST_FRAME: U1.14 (PB0); also elsewhere on the board
RXD: U1.2 (PD0); also elsewhere on the board
SCLK: U1.19 (PB5); also elsewhere on the board
TXD: U1.3 (PD1); also elsewhere on the board
VCC: C3.1, Q1.3 (S), R2.1, U1.7 (VCC), U1.20 (AVCC); also elsewhere on the board
VREF: C4.1, Q1.1 (D); also elsewhere on the board
~RESET: SW1.1, U1.1 (~RESET/PC6); also elsewhere on the board

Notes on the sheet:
Reset Switch
Microcontroller
Decoupling Capacitors
VREF Cutoff Circuit

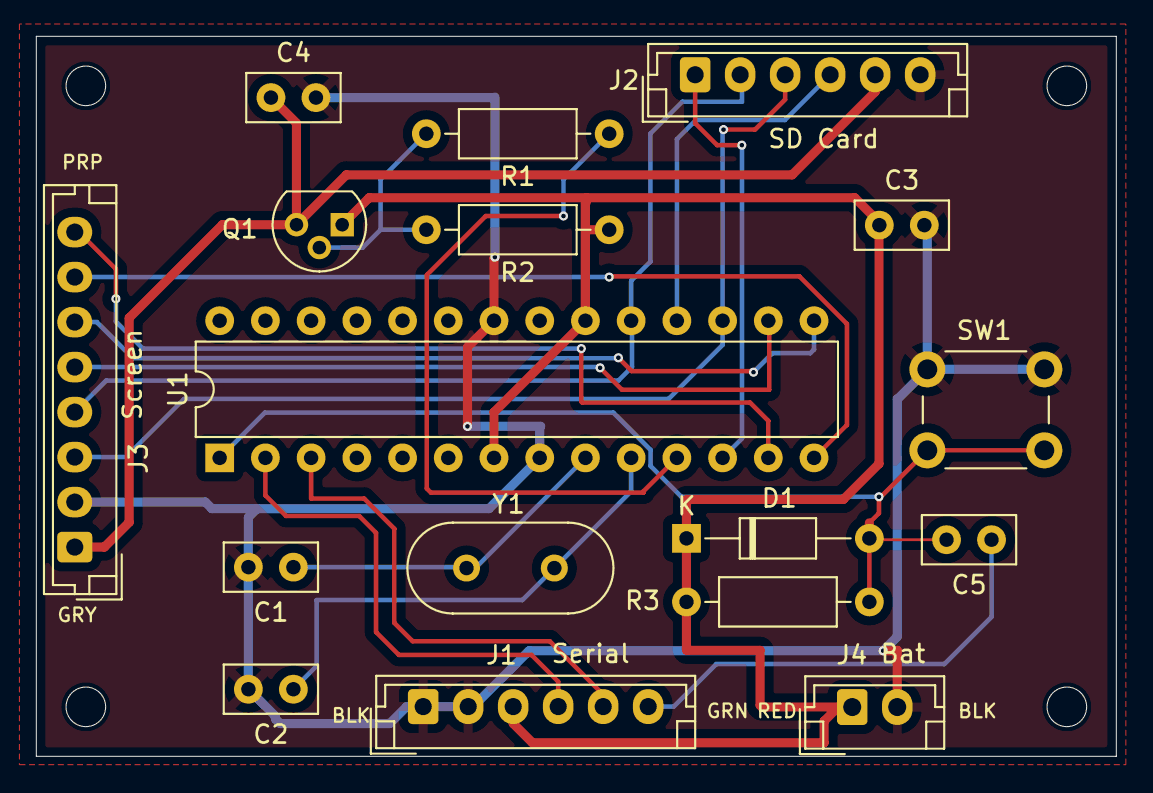
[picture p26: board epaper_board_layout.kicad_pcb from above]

Board: 2 copper layers, 60.0 x 40.0 mm, 17 parts (0 on the bottom side), 19 nets.

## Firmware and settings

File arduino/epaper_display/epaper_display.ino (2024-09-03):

/******************************************************************************
File: epaper_display.ini
******************************************************************************
MIT License

Copyright (c) 2023 Robert L Gorsegner II

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
THE SOFTWARE IS PROVIDED "AS IS", WITHOUT WARRANTY OF ANY KIND, EXPRESS OR
IMPLIED, INCLUDING BUT NOT LIMITED TO THE WARRANTIES OF MERCHANTABILITY,
FITNESS FOR A PARTICULAR PURPOSE AND NONINFRINGEMENT. IN NO EVENT SHALL THE
AUTHORS OR COPYRIGHT HOLDERS BE LIABLE FOR ANY CLAIM, DAMAGES OR OTHER
LIABILITY, WHETHER IN AN ACTION OF CONTRACT, TORT OR OTHERWISE, ARISING FROM,
OUT OF OR IN CONNECTION WITH THE SOFTWARE OR THE USE OR OTHER DEALINGS IN THE
SOFTWARE.
******************************************************************************/
#include <Arduino.h>
#include <SD.h>
#include <LowPower.h>
#include <SPI.h>
#include <EEPROM.h>
#include <avr/pgmspace.h>
#include "epd7in3f.h"
#include "epdif.h"
#include "read_bmp.h"
#include "eeprom_data.h"
#include "debug.h"
#include "picture_index.h"


// Definitions
#define PIN_POWER_SELECT    5
#define PIN_SD_CHIP_SELECT  6
#define PIN_MOSI            11
#define PIN_SCLK            13

#define SECONDS_IN_A_DAY  86400
#define SECONDS_TO_DISPLAY 135
#define NUMBER_OF_SLEEP_LOOPS   ((SECONDS_IN_A_DAY - SECONDS_TO_DISPLAY)/8)

// Function declarations.
int get_next_file_handle(SDFile &sdFile);
inline void beginSpiTransaction() __attribute__((always_inline));
inline void endSpiTransaction() __attribute__((always_inline));
void sendQuarterRow(Epd *pEpd, char *buffer);

// Global variables
long sleep_loops = 0;

/******************************************************************************
function : 
      Setup
******************************************************************************/
void setup() {
  // put your setup code here, to run once:
  // Set up serial port baud rate for debug
  Debug::serialBegin(9600);

  Debug::printEepromErrorInfo();

  int pictureIndex = EepromData::readPictureIndex();

  #ifdef SERIAL_DEBUG
  Debug::printProgMem(PSTR("Starting off from picture index "));
  Serial.print(pictureIndex, DEC);
  Serial.print("\r\n");
  #endif // SERIAL_DEBUG

  PictureIndex::setPictureIndex(pictureIndex);
}

/******************************************************************************
function : 
      Main loop
******************************************************************************/
void loop() {

  powerUpPeripherals();

  updateDisplayWithNewPicture();

  powerDownPeripherals();

  while(sleep_loops < NUMBER_OF_SLEEP_LOOPS) {
    Debug::printProgMem(PSTR("Sleeping\r\n"));

    Debug::serialFlush();
    LowPower.powerDown(SLEEP_8S, ADC_OFF, BOD_OFF); 
    sleep_loops++;

    Debug::printProgMem(PSTR("Waking\r\n"));
  }
  sleep_loops = 0;
}

/******************************************************************************
  Update the display with a new picture
******************************************************************************/
void updateDisplayWithNewPicture() {
  bool bmpFileInit = false;
  Epd epd;
  SDFile bmpFile;

  Debug::printProgMem(PSTR("epd.Init()\r\n"));
  if (epd.Init() != SUCCESS) {
    Debug::printProgMem(PSTR("e-Paper init failed.\r\n"));
    Debug::error(ERRORCODE_EPAPER_INIT_FAILED);
    return;
  }

  // Clear the display.
  Debug::printProgMem(PSTR("e-Paper Clear\r\n"));
  beginSpiTransaction();
  epd.Clear(EPD_7IN3F_WHITE);
  endSpiTransaction();

  SD.begin(SPI_QUARTER_SPEED, PIN_SD_CHIP_SELECT);
  // getNextFileHandle has the error handling code in it.
  if( getNextFileHandle(bmpFile) == FAILURE) {
    goto cleanup;
  }
  bmpFileInit = true;

  Debug::printProgMem(PSTR("Display Image\r\n"));
  displayImage(&epd, bmpFile);
  // epd.EPD_7IN3F_Show7Block();

  // Delay 3 seconds while the image shows on the screen.
  delay(3000);

cleanup:  
  Debug::printProgMem(PSTR("EPaper Sleep...\r\n"));
  beginSpiTransaction();
  epd.Sleep();
  endSpiTransaction();

  // Close the file handle.
  if(bmpFileInit) {
    bmpFile.close();
  }

  // Close the SD Card.
  SD.end();
  PictureIndex::updateInUsePictureIndex();
}

/******************************************************************************
  Power up the SDCARD and E-Hat
******************************************************************************/
void powerUpPeripherals() {
  Debug::printProgMem(PSTR("powerUpPeripherals\r\n"));

  // Set the SDCARD CS, SCLK and MOSI pins high so the SD CARD doesn't start 
  // reading the SPI bus when powered up. Flush every debug serial port 
  // transaction so that if there is a problem the last message is logged.
  Debug::printProgMem(PSTR("pinMode(PIN_SD_CHIP_SELECT, OUTPUT)\r\n"));
  Serial.flush();
  pinMode(PIN_SD_CHIP_SELECT, OUTPUT);

  Debug::printProgMem(PSTR("digitalWrite(PIN_SD_CHIP_SELECT, HIGH)\r\n"));
  Serial.flush();
  digitalWrite(PIN_SD_CHIP_SELECT, HIGH);

  Debug::printProgMem(PSTR("pinMode(PIN_SCLK, OUTPUT)\r\n"));
  Serial.flush();
  pinMode(PIN_SCLK, OUTPUT);

  Debug::printProgMem(PSTR("digitalWrite(PIN_SCLK, HIGH)\r\n"));
  Serial.flush();
  digitalWrite(PIN_SCLK, HIGH);
  
  Debug::printProgMem(PSTR("pinMode(PIN_MOSI, OUTPUT)\r\n"));
  Serial.flush();
  pinMode(PIN_MOSI, OUTPUT);

  Debug::printProgMem(PSTR("digitalWrite(PIN_MOSI, HIGH)\r\n"));
  Serial.flush();
  digitalWrite(PIN_MOSI, HIGH);


  // Turn on the peripheral power by setting power select low.
  Debug::printProgMem(PSTR("pinMode(PIN_POWER_SELECT, OUTPUT)\r\n"));
  Serial.flush();
  pinMode(PIN_POWER_SELECT, OUTPUT);
  digitalWrite(PIN_POWER_SELECT, LOW);

  // Allow a small delay for the peripherals to get power.
  Debug::printProgMem(PSTR("delay(2)\r\n"));
  delay(2);

  Debug::printProgMem(PSTR("-powerUpPeripherals\r\n"));
}

/******************************************************************************
  Power down the SDCARD and E-Hat
******************************************************************************/
void powerDownPeripherals() {
  Debug::printProgMem(PSTR("powerDownPeripherals\r\n"));
  // Turn off the peripheral power by setting the power select GPIO high.  
  // The power will remain off while sleeping.
  digitalWrite(PIN_POWER_SELECT, HIGH);

  
  // If SCLK, MOSI or the CS lines are high, the SD Card board will draw power on some
  // SD Card boards.  This can be prevented by setting these lines as inputs.
  pinMode(PIN_SCLK, INPUT);
  pinMode(PIN_MOSI, INPUT);
  pinMode(PIN_SD_CHIP_SELECT, INPUT);
}

/******************************************************************************
  Get next file.  Remember to close the file handle after use.

  @param[out] sdFile
         Pointer to the display object.

  @retval SUCCESS
  @retval FAILURE
******************************************************************************/
int getNextFileHandle(SDFile &sdFile) {
  char filename[MAX_8_3_FILENAME_SIZE];

  // Get the next filename.
  Debug::printProgMem(PSTR("Get the next filename\r\n"));
  PictureIndex::getBmpFilename(filename);

  Debug::printProgMem(PSTR("Opening file "));
  Debug::print(filename);
  Debug::print("\r\n");
  sdFile = SD.open(filename, FILE_READ);
  if(sdFile) {
    Debug::printProgMem(PSTR("File opened.\r\n"));
    PictureIndex::incrementPictureIndex();
    EepromData::savePictureIndex();
    return SUCCESS;
  }

  if(PictureIndex::getPictureIndex()==0) {
    // Do not log the first picture to the eeprom because this is easy to reproduce.
    Debug::printProgMem(PSTR("Failed to open file pic_000.bmp.\r\n"));
    return FAILURE;
  } 

  Debug::printProgMem(PSTR("Failed to open file.\r\n"));
  sdFile.close();

  // Sent the picture index to the original.
  PictureIndex::clearPictureIndex();
  PictureIndex::updateInUsePictureIndex();
  PictureIndex::getBmpFilename(filename);

  Debug::printProgMem(PSTR("Opening file "));
  Debug::print(filename);
  Debug::printProgMem(PSTR("\r\n"));
  sdFile = SD.open(filename, FILE_READ);
  if(sdFile) {
    Debug::printProgMem(PSTR("File opened."));
    PictureIndex::incrementPictureIndex();
    EepromData::savePictureIndex();
    return SUCCESS;
  }

  Debug::printProgMem(PSTR("Failed to open any bmp file.\r\n"));
  return FAILURE;
}

/******************************************************************************
  Displays the image.

  @param pEpd
         Pointer to the display object.
  @param filename
         Filename of the bitmap.

  @retval SUCCESS
  @retval FAILURE
******************************************************************************/
int displayImage(Epd * pEpd, SDFile & bmpFile) {
  int ret = SUCCESS;
  // Send the command to start writing the data buffer.
  Debug::printProgMem(PSTR("pEpd->SendCommand(0x10)\r\n"));
  beginSpiTransaction();
  pEpd->SendCommand(0x10);
  endSpiTransaction();

  // Create the ReadBMP class
  ReadBMP readbmp(&bmpFile);

  if (readbmp.parseHeader() != SUCCESS) {
    // Close the data file
    ret = FAILURE;
    goto display_image_cleanup;
  }

  if(readbmp.width() != EPD_WIDTH || readbmp.height() != EPD_HEIGHT ) {
    Debug::printProgMem(("Invalid image size.\r\n"));
    Debug::error(ERRORCODE_BMP_INVALID_IMAGE_SIZE);
    ret = FAILURE;
    goto display_image_cleanup;
  }

  {
    char quarterLineBuffer[EPD_WIDTH/4];
    for(int row = 0; row < EPD_HEIGHT; row++) {
      for(int quarter = 0; quarter < 4 ; quarter++) {
        // Read in one half row of data. Callee handles error message.
        if(readbmp.readQuarterLine(quarterLineBuffer) == FAILURE) {
          ret = FAILURE;
          goto display_image_cleanup;
        }

        beginSpiTransaction();
        // Write out one half row to the screen.
        sendQuarterRow(pEpd, quarterLineBuffer);
        endSpiTransaction();
      }
    }
  }

  Debug::printProgMem(PSTR("pEpd->TurnOnDisplay()\r\n"));
  beginSpiTransaction();
  ret = pEpd->TurnOnDisplay();
  if( ret== FAILURE) {
    Debug::printProgMem(PSTR("TurnOnDisplay Failed\r\n."));
    Debug::error(ERRORCODE_EPAPER_FAILED_TURN_ON_DISPLAY);
  }

  endSpiTransaction();

display_image_cleanup:
  // Close the data file
  bmpFile.close();

  // Show the image.
  return ret;
}

/******************************************************************************
  Begin a spi transaction for the e-paper screen
******************************************************************************/
void beginSpiTransaction() {
  SPI.beginTransaction(SPISettings(EPD_SPI_SPEED, MSBFIRST, SPI_MODE0));
}

/******************************************************************************
  End a spi transaction for the e-paper screen
******************************************************************************/
void endSpiTransaction() {
  SPI.endTransaction();
}

/******************************************************************************
  Send a half row.  A full row takes up to much memory on the arduino.

  @param buffer A buffer for the half row.

******************************************************************************/
void printHalfRow(char *buffer) {
  #ifdef SERIAL_DEBUG
  for(int col = 0; col< EPD_WIDTH /4 ; col++ ) {
    Serial.print(buffer[col], HEX);
    Serial.print(",");
  }
  Serial.print("\r\n");
  #else
  // Gets rid of the warning for an unused variable.
  (void *)buffer;
  #endif // SERIAL_DEBUG
}

/******************************************************************************
  Sends a quarter row of data to the device.

  @param pEpd
         Pointer to the display object.
  @param buffer
         The buffer for one half line.          
******************************************************************************/
void sendQuarterRow(Epd *pEpd, char *buffer) {
  for(int col = 0; col< EPD_WIDTH /8 ; col++ ) {
    pEpd->SendData(buffer[col]);
  }
}

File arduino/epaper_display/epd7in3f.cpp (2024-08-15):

/*****************************************************************************
* | File        :   EPD_7in3f.c
* | Author      :   Waveshare team
* | Function    :   7.3inch e-Paper (F)
* | Info        :
*----------------
* | This version:   V1.0
* | Date        :   2022-10-21
* | Info        :
* -----------------------------------------------------------------------------
#
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
******************************************************************************/

#include <stdlib.h>
#include <SPI.h>
#include "epd7in3f.h"
#include "debug.h"

Epd::~Epd() {
};

Epd::Epd() {
    reset_pin = RST_PIN;
    dc_pin = DC_PIN;
    cs_pin = CS_PIN;
    busy_pin = BUSY_PIN;
    width = EPD_WIDTH;
    height = EPD_HEIGHT;
};

/******************************************************************************
function :  Initialize the e-Paper register
parameter:
******************************************************************************/
int Epd::Init(void) {
    int ret = SUCCESS;
    if (IfInit() != 0) {
        return FAILURE;
    }
    SPI.beginTransaction(SPISettings(EPD_SPI_SPEED, MSBFIRST, SPI_MODE0));
    Reset();
    DelayMs(20);
    // Typically this wait is less than a second.
    ret = EPD_7IN3F_BusyHigh(2L*1000L);
    if(ret == FAILURE) {
      goto end_init;
    }
    
    SendCommand(0xAA);    // CMDH
    SendData(0x49);
    SendData(0x55);
    SendData(0x20);
    SendData(0x08);
    SendData(0x09);
    SendData(0x18);

    SendCommand(0x01);
    SendData(0x3F);
    SendData(0x00);
    SendData(0x32);
    SendData(0x2A);
    SendData(0x0E);
    SendData(0x2A);

    SendCommand(0x00);
    SendData(0x5F);
    SendData(0x69);

    SendCommand(0x03);
    SendData(0x00);
    SendData(0x54);
    SendData(0x00);
    SendData(0x44); 

    SendCommand(0x05);
    SendData(0x40);
    SendData(0x1F);
    SendData(0x1F);
    SendData(0x2C);

    SendCommand(0x06);
    SendData(0x6F);
    SendData(0x1F);
    SendData(0x16);
    SendData(0x25);

    SendCommand(0x08);
    SendData(0x6F);
    SendData(0x1F);
    SendData(0x1F);
    SendData(0x22);

    SendCommand(0x13);    // IPC
    SendData(0x00);
    SendData(0x04);

    SendCommand(0x30);
    SendData(0x02);

    SendCommand(0x41);     // TSE
    SendData(0x00);

    SendCommand(0x50);
    SendData(0x3F);

    SendCommand(0x60);
    SendData(0x02);
    SendData(0x00);

    SendCommand(0x61);
    SendData(0x03);
    SendData(0x20);
    SendData(0x01); 
    SendData(0xE0);

    SendCommand(0x82);
    SendData(0x1E); 

    SendCommand(0x84);
    SendData(0x00);

    SendCommand(0x86);    // AGID
    SendData(0x00);

    SendCommand(0xE3);
    SendData(0x2F);

    SendCommand(0xE0);   // CCSET
    SendData(0x00); 

    SendCommand(0xE6);   // TSSET
    SendData(0x00);
end_init:
    SPI.endTransaction();
    return ret;
}

/**
 *  @brief: basic function for sending commands
 */
void Epd::SendCommand(unsigned char command) {
    DigitalWrite(dc_pin, LOW);
    SpiTransfer(command);
}

/**
 *  @brief: basic function for sending data
 */
void Epd::SendData(unsigned char data) {
    DigitalWrite(dc_pin, HIGH);
    SpiTransfer(data);
}

/**
 *  @brief: Waits for busy to go low.
 *
 */
int Epd::EPD_7IN3F_BusyHigh(long maxWaitMs)// If BUSYN=0 then waiting
{
    long ms = 0;
    while(!DigitalRead(BUSY_PIN)) {
        DelayMs(1);
        if(ms > maxWaitMs) {
          return FAILURE;
        }
        ms++;
    }
    return SUCCESS;
}

/**
 *  @brief: module reset.
 *          often used to awaken the module in deep sleep,
 *          see Epd::Sleep();
 */
void Epd::Reset(void) {
    DigitalWrite(reset_pin, HIGH);
    DelayMs(20);   
    DigitalWrite(reset_pin, LOW);                //module reset    
    DelayMs(1);
    DigitalWrite(reset_pin, HIGH);
    DelayMs(20);    
}

int Epd::TurnOnDisplay(void) {
    SendCommand(0x04);  // POWER_ON
    // Typically this wait is less then 1 second.
    if(EPD_7IN3F_BusyHigh(2L * 1000L) == FAILURE){
      return FAILURE;
    }


    delay(100);
    
    SendCommand(0x12);  // DISPLAY_REFRESH
    SendData(0x00);
    // Typically this wait is less then 1 minute.
    if(EPD_7IN3F_BusyHigh(120L * 1000L) == FAILURE){
      return FAILURE;
    }

    delay(100);

    SendCommand(0x02);  // POWER_OFF
    SendData(0x00);
    // Typically this wait is less then 1 second.
    if(EPD_7IN3F_BusyHigh(2L * 1000L) == FAILURE){
      return FAILURE;
    }
    return SUCCESS;
}

/******************************************************************************
function :  Sends the image buffer in RAM to e-Paper and displays
parameter:
******************************************************************************/
void Epd::EPD_7IN3F_Display(const UBYTE *image) {
    unsigned long i,j;
    
    SendCommand(0x10);
    for(i=0; i<height; i++) {
        for(j=0; j<width/2; j++) {
            SendData(image[j + width*i]);
          }
    }
    
    TurnOnDisplay();
}
/******************************************************************************
function :  Sends the part image buffer in RAM to e-Paper and displays
parameter:
******************************************************************************/
void Epd::EPD_7IN3F_Display_part(const UBYTE *image, UWORD xstart, UWORD ystart, 
                                        UWORD image_width, UWORD image_heigh)
{
    unsigned long i,j;

    SendCommand(0x10);
    for(i=0; i<height; i++) {
        for(j=0; j< width/2; j++) {
            if(i<image_heigh+ystart && i>=ystart && j<(image_width+xstart)/2 && j>=xstart/2) {
              SendData(pgm_read_byte(&image[(j-xstart/2) + (image_width/2*(i-ystart))]));
            }
                  else {
                      SendData(0x11);
                  }
            }
    }
    TurnOnDisplay();
}

/******************************************************************************
function :  show 7 kind of color block
parameter:
******************************************************************************/
void Epd::EPD_7IN3F_Show7Block(void)
{
    unsigned long i, j, k;
    unsigned char const Color_seven[8] = 
    {EPD_7IN3F_BLACK, EPD_7IN3F_BLUE, EPD_7IN3F_GREEN, EPD_7IN3F_ORANGE,
    EPD_7IN3F_RED, EPD_7IN3F_YELLOW, EPD_7IN3F_WHITE, EPD_7IN3F_WHITE};

    SendCommand(0x10);
    for(i=0; i<240; i++) {
        for(k = 0 ; k < 4; k ++) {
            for(j = 0 ; j < 100; j ++) {
                SendData((Color_seven[k]<<4) |Color_seven[k]);
            }
        }
    }
    
    for(i=0; i<240; i++) {
        for(k = 4 ; k < 8; k ++) {
            for(j = 0 ; j < 100; j ++) {
                SendData((Color_seven[k]<<4) |Color_seven[k]);
            }
        }
    }
    TurnOnDisplay();
}
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

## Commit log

2023-12-12 Added picture frame border stl
    [epicture_frame-Part_Border.stl]
2023-12-12 Minor Documentation Changes
    [epicture_frame.FCStd, picture_frame_border.FCStd]
2024-01-08 Moved arduino code to seperate epaper directory so that the Arduino IDE doesn't complain.
    [debug.cpp, epaper_display.ino, epd7in3f.cpp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]
2024-01-09 Fixed problem where current was leaking through the MOSI and CS lines in the SD Card board.
    [epaper_display.ino]
2024-01-09 Added battery consumption information to documentation.
2024-01-09 Updated board schematic and layout because of FET labeled incorrectly in schematic.
    [epaper_board_layout-B_Mask.gbs, epaper_board_layout-B_Paste.gbp, epaper_board_layout-B_Silkscreen.gbo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]
2024-02-28 Testing real Arduino build script.
2024-02-28 Try removing SPI library. May be built in.
2024-02-28 Adding Arduino_builtin library.
2024-02-28 Fix headerfile reference case for linux builds
2024-02-28 Removing arduino pro from being compiled.
2024-02-29 Found a couple mre README.md issues.
2024-08-15 Added better error handling to display code.
    [epaper_display.ino, epd7in3f.cpp]
2024-08-25 Changed powerup sequence.
2024-09-03 Added the ability to produce test images for battery in testing.

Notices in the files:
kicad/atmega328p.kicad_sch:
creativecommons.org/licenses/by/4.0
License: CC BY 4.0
